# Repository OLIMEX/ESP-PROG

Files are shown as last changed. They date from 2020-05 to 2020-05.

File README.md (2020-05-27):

# ESP-PROG
ESP-PROG is USB programmer for ESP8266 and ESP32.

Product page: https://www.olimex.com/Products/IoT/Programmer/ESP-PROG/open-source-hardware

## Licensee
* Hardware is released under CERN Open Hardware Licence Version 2 -
Strongly Reciprocal
* Software is released under GPL3 Licensee
* Documentation is released under CC BY-SA 3.0

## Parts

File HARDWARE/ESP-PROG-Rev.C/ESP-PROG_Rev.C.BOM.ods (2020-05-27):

Designation | Quantity | Designator | Package
Q12MHz/20pF/30ppm/2P/HC-49SM(SMD) | 1 | Y1 | TSX-3.2x2.5mm_GND(3)
ME6210 | 1 | U2 | SOT-89
MISB-SWMM-5B-LF(USB_MICRO) | 1 | USB1 | USB-MICRO_MISB-SWMM-5B_LF
SMD ИС CH340T SSOP20 | 1 | U1 | SSOP-20W
SMD РЕЗ 0402 100 OHM 5% | 2 | R4,R3 | R_0402_5MIL_DWS
SMD РЕЗ 0402 1 K 5% | 2 | R2,R1 | R_0402_5MIL_DWS
BC817-40(SOT23) | 2 | Q2,Q1 | SOT23
СЪЕДИНИТЕЛ WU06S | 1 | CON1 | WU06S
SMD КОНД 0402 27 PF C0G 50VDC 5% | 2 | C4,C2 | C_0402_5MIL_DWS
SMD КОНД 0603 2.2 UF X5R 6.3VDC 10% | 2 | C3,C1 | C_0603_5MIL_DWS
РЕЙКА 1 X 40 (HN 1X40) | 7/40 | CON6

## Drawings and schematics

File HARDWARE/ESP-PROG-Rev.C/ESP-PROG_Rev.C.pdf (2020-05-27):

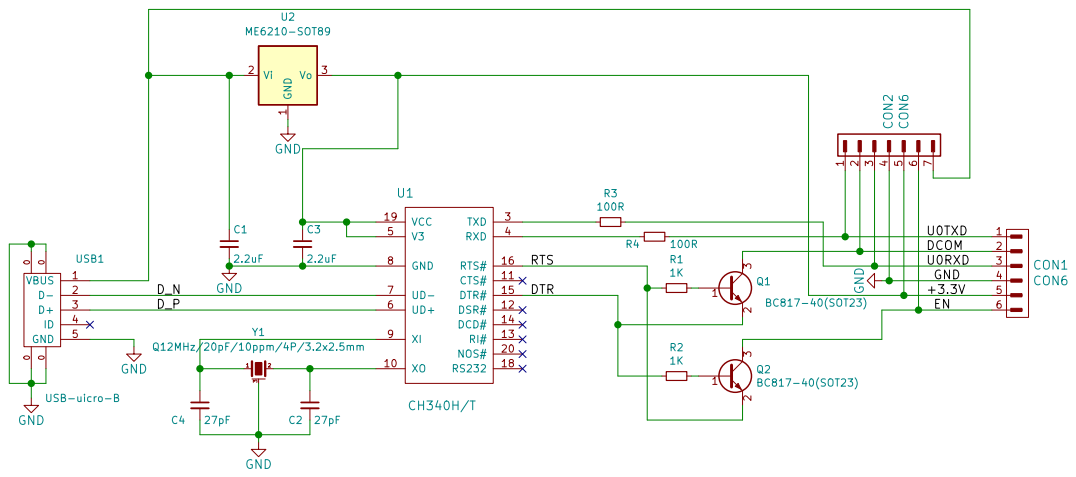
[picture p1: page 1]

DCOM 2
U0RXD GND 3

File: ESP-PROG_Rev.C.sch Sheet: /
Id: 1/1 Title:

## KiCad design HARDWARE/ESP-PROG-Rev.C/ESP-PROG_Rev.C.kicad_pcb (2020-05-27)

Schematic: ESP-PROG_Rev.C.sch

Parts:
C1, C3: 2.2uF; C_0603_5MIL_DWS
C2, C4: 27pF; C_0402_5MIL_DWS
CON1: CON6; WU06SM
CON2: CON6; HN1x6
Q1, Q2: BC817-40(SOT23); SOT23
R1, R2: 1K; R_0402_5MIL_DWS
R3, R4: 100R; R_0402_5MIL_DWS
U1: CH340H/T; SSOP-20W
U2: ME6210-SOT89; SOT89
USB1: USB-uicro-B; USB-MICRO_MISB-SWMM-5B_LF
Y1: Q12MHz/20pF/10ppm/4P/3.2x2.5mm; TSX-3.2x2.5mm_GND(3)

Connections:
/+3.3V: C3.1, CON1.5, CON2.5, U1.5 (V3), U1.19 (VCC), U2.3
/DCOM: CON1.2, CON2.2, Q1.3
/DTR: Q1.2, R2.2, U1.15 (DTR#)
/D_N: U1.7 (UD-), USB1.2 (D-)
/D_P: U1.6 (UD+), USB1.3 (D+)
/EN: CON1.6, CON2.6, Q2.3
/RTS: Q2.2, R1.2, U1.16 (RTS#)
/U0RXD: CON1.3, CON2.3, R3.1
/U0TXD: CON1.1, CON2.1, R4.1
GND: C1.2, C2.2, C3.2, C4.2, CON1.4, CON2.4, U1.8 (GND), U2.1, USB1.0, USB1.5 (GND), Y1.3
unnamed: C1.1, CON2.7, U2.2, USB1.1 (VBUS)
unnamed: C2.1, U1.10 (XO), Y1.2
unnamed: C4.1, U1.9 (XI), Y1.1
unnamed: Q1.1, R1.1
unnamed: Q2.1, R2.1
unnamed: R3.2, U1.3 (TXD)
unnamed: R4.2, U1.4 (RXD)

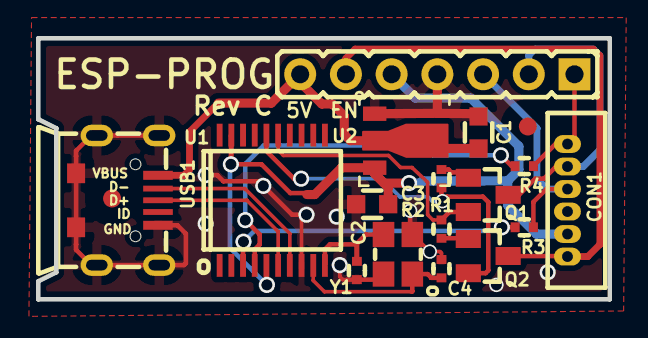
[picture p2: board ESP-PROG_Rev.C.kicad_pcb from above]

Board: 2 copper layers, 31.8 x 14.5 mm, 18 parts (0 on the bottom side), 17 nets.

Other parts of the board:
Ref*: Val**; Fiducial1x3_transp
Ref*#2: Val**; Fiducial1x3_transp

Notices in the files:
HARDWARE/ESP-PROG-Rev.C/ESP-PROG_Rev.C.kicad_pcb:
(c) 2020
